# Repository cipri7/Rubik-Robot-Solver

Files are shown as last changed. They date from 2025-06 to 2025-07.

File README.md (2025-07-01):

# Rubik-Robot-Solver

This project solves a Rubik's Cube using a combination of computer vision and robotics. It scans the cube's faces using a camera, determines the cube's state, calculates the solution, and then sends the solution to an Arduino-controlled robot to execute the moves.

The robot in action: https://youtu.be/shVyaf8nSuM?si=lHKmhP8OhFEYzAJg

## Prerequisites

Before you begin, ensure you have the following:

*   **Python 3.6+**
*   **pip** (Python package installer)
*   **A webcam** connected to your computer.
*   **An Arduino** connected to your computer.
*   **6x Nema17 Stepper Motors**
*   **6x A4988 Drivers**
*   **6x 100uF Capacitors**
*   **12V Power Supply**
*   **A Rubik's Cube**

## Installation

1.  **Clone the repository:**

    ```bash
    git clone <repository_url>
    cd Rubik-Robot-Solver
    ```

2.  **Install the required Python packages:**

    ```bash
    pip install -r requirements.txt
    ```

3. **Upload motor_solver.c to Arduino**

4. **Build the electronic circuit as in the schematic file**
5. **Assemble the robot.**

## Configuration

1.  **Calibration:**
    *   Run the `scan_cube.py` script to calibrate the color detection. This step is crucial for accurate color recognition.
    *   The script will prompt you to show each face of the cube (W, R, G, Y, O, B) to the camera. Center the face and press SPACE to capture its color.
    *   If you have a pre-existing calibration, you can skip the calibration by pressing any key other than 'c' when prompted.
    *   The calibration data is saved in `src/calibration.json`.

2.  **Arduino Port:**
    *   Modify the `ARDUINO_PORT` variable in [`src/visualize_cube.py`](https://github.com/cipri7/Rubik-Robot-Solver/blob/main/src/visualize_cube.py) to match the serial port of your Arduino.

    ```python
    # From src/visualize_cube.py
    ARDUINO_PORT = "/dev/cu.usbmodem1101"  # Update as needed
    ```

    *   You can usually find the correct port in the Arduino IDE.

## Usage

1.  **Scan the Cube:**

    *   Run the main script to start the scanning process:

    ```bash
    python src/main.py
    ```

    *   The `scan_cube.py` script will guide you through scanning each face of the Rubik's Cube. Follow the on-screen prompts.
    *   The scanned state will be saved in [`src/scanned_state.json`](https://github.com/cipri7/Rubik-Robot-Solver/blob/main/src/scanned_state.json).

2.  **Visualize and Solve:**

    *   After scanning, the `visualize_cube.py` script will open a window displaying the scanned cube.
    *   You can manually correct any misidentified colors by clicking on the tiles and selecting the correct color.
    *   Press `C` to confirm the cube state. This will print the Kociemba string representation of the cube to the console.
    *   Press `S` to solve the cube. This will calculate the solution using the `kociemba` library and send the solution to the Arduino.

## Troubleshooting

*   **Webcam Issues:** If the webcam is not detected, ensure it is properly connected and that no other applications are using it.  You may need to adjust the `camera_id` in [`src/cube_scanner.py`](https://github.com/cipri7/Rubik-Robot-Solver/blob/main/src/cube_scanner.py).
*   **Color Calibration:** If the colors are not being recognized correctly, recalibrate the color detection using the `scan_cube.py` script. Ensure good lighting conditions during calibration.
*   **Serial Communication:** If the solution is not being sent to the Arduino, double-check the `ARDUINO_PORT` in [`src/visualize_cube.py`](https://github.com/cipri7/Rubik-Robot-Solver/blob/main/src/visualize_cube.py) and ensure the Arduino is properly connected and running the appropriate firmware.

## Code Structure

*   [`src/main.py`](https://github.com/cipri7/Rubik-Robot-Solver/blob/main/src/main.py): Main entry point of the application.
*   [`src/scan_cube.py`](https://github.com/cipri7/Rubik-Robot-Solver/blob/main/src/scan_cube.py): Handles cube scanning and color calibration.
*   [`src/cube_scanner.py`](https://github.com/cipri7/Rubik-Robot-Solver/blob/main/src/cube_scanner.py): Contains the `CubeScanner` class for capturing cube faces.
*   [`src/color_classifier.py`](https://github.com/cipri7/Rubik-Robot-Solver/blob/main/src/color_classifier.py): Contains the `ColorClassifier` class for identifying colors.
*   [`src/visualize_cube.py`](https://github.com/cipri7/Rubik-Robot-Solver/blob/main/src/visualize_cube.py): Visualizes the scanned cube and sends the solution to the Arduino.
*   [`src/motor_controller.py`](https://github.com/cipri7/Rubik-Robot-Solver/blob/main/src/motor_controller.py): Manages serial communication with the Arduino.
*   [`src/calibration.json`](https://github.com/cipri7/Rubik-Robot-Solver/blob/main/src/calibration.json): Stores color calibration data.
*   [`src/scanned_state.json`](https://github.com/cipri7/Rubik-Robot-Solver/blob/main/src/scanned_state.json): Stores the scanned state of the cube.

## Credits

This project utilizes the kociemba library for solving the Rubik's Cube.

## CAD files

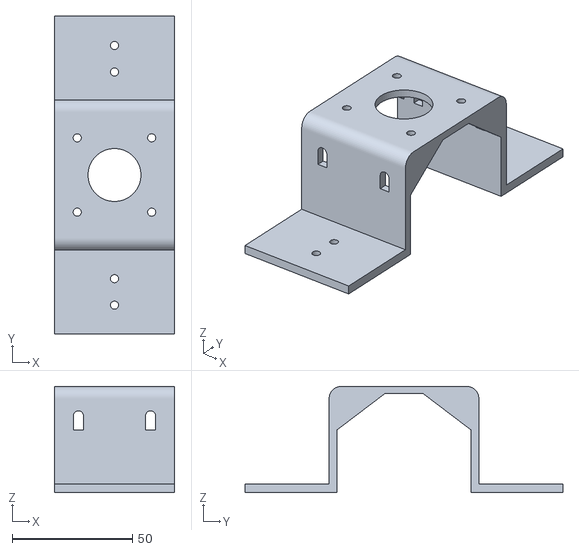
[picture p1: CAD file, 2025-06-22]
stl_files/motor_low_mount.stl
50.0 x 132.3 x 44.2

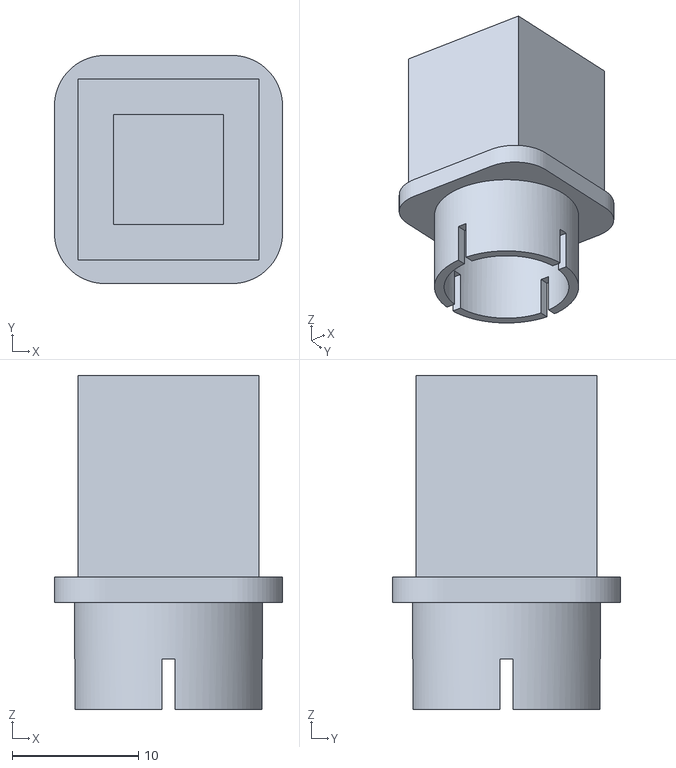
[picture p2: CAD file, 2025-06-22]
stl_files/cube_adapter_B.stl
18.1 x 18.1 x 26.5

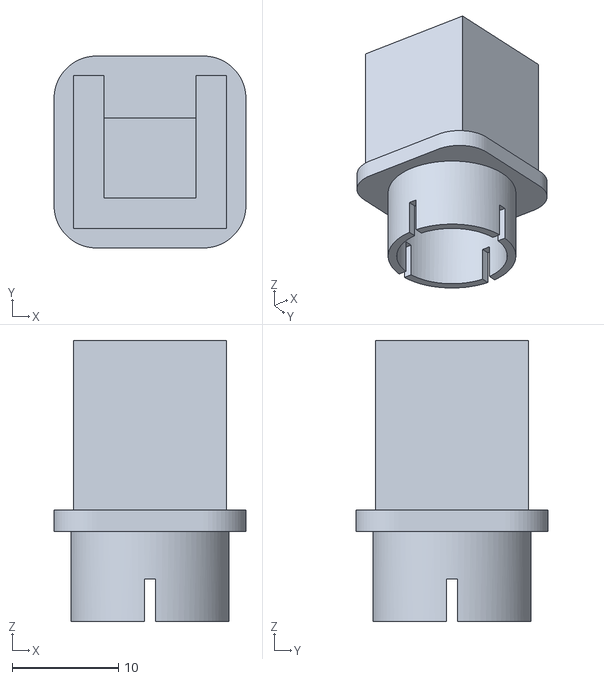
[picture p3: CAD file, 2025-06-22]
stl_files/cube_adapter_A.stl
18.1 x 18.1 x 26.5

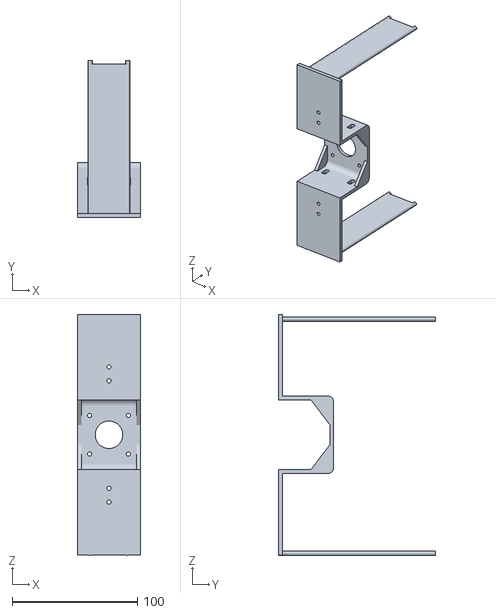
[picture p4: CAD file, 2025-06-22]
stl_files/motor_top_mount.stl
50.0 x 125.8 x 192.7

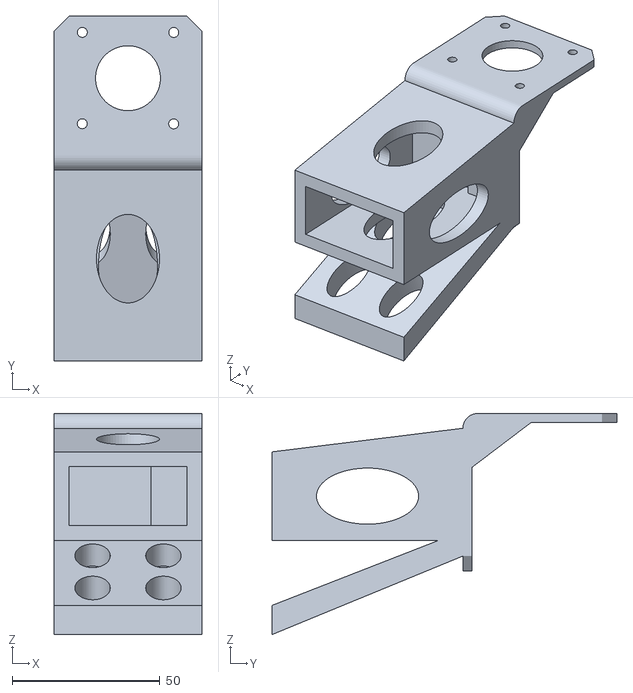
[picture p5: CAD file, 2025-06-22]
stl_files/motor_side_mount.stl
50.0 x 116.7 x 74.9

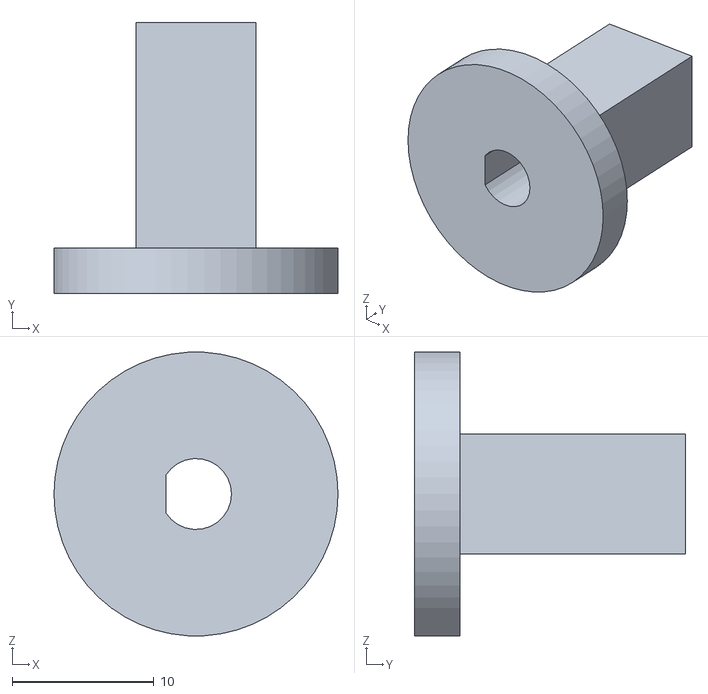
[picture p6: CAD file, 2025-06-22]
stl_files/motor_shaft_support.stl
20.0 x 19.0 x 20.0

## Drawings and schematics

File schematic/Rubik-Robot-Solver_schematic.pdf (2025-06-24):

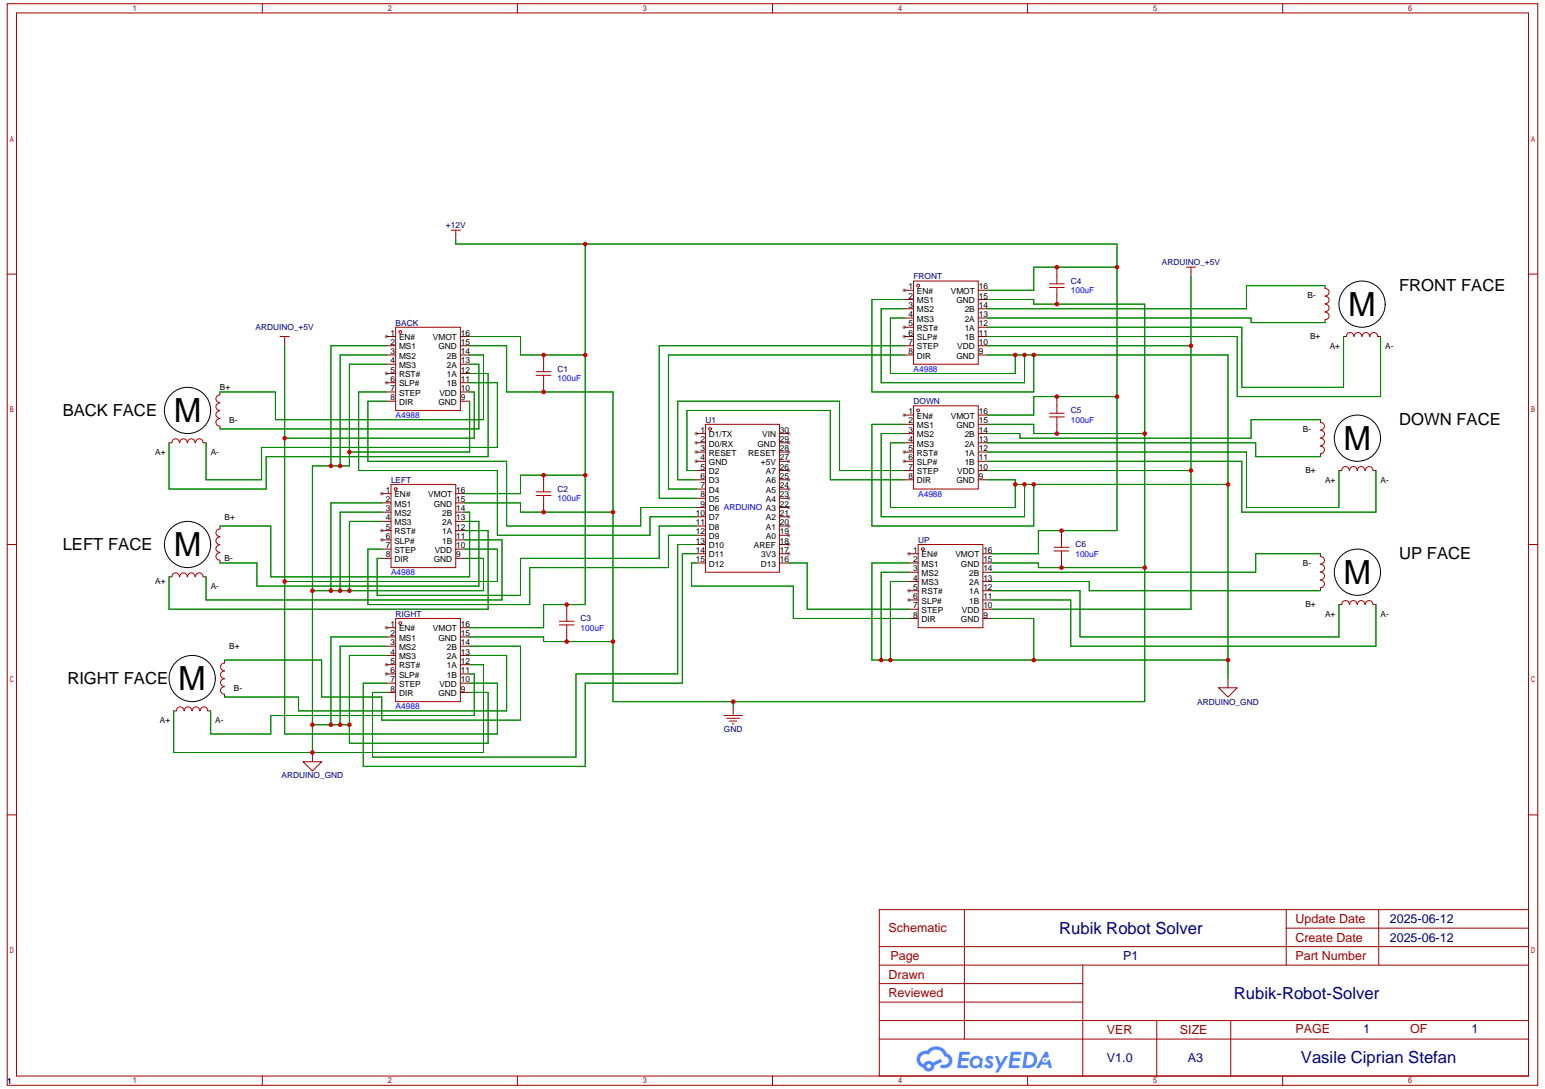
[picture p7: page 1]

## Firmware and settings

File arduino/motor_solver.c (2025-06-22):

#include <AccelStepper.h>

// Stepper motors (STEP, DIR)
AccelStepper stepperU(1, 13, 12);   // Up
AccelStepper stepperD(1, 3, 2);     // Down
AccelStepper stepperF(1, 5, 4);     // Front
AccelStepper stepperB(1, 7, 6);     // Back
AccelStepper stepperL(1, 9, 8);     // Left
AccelStepper stepperR(1, 11, 10);   // Right

// Steps per 90-degree turn
#define STEPS_PER_90_DEG 50 

String inputCommand = "";

void setup() {
  Serial.begin(115200);
  Serial.println("Rubik's Cube Stepper Controller Ready.");
  Serial.println("Enter move string (e.g. UDBFLRRL2UBD3R2U):");

  // Set max speed and acceleration
  stepperU.setMaxSpeed(5000); stepperU.setAcceleration(5000);
  stepperD.setMaxSpeed(5000); stepperD.setAcceleration(5000);
  stepperF.setMaxSpeed(5000); stepperF.setAcceleration(5000);
  stepperB.setMaxSpeed(5000); stepperB.setAcceleration(5000);
  stepperL.setMaxSpeed(5000); stepperL.setAcceleration(5000);
  stepperR.setMaxSpeed(5000); stepperR.setAcceleration(5000);
}

void moveMotor(AccelStepper &motor, int steps) {
  motor.move(steps);
  while (motor.distanceToGo() != 0) {
    motor.run();
  }
}

void processMoves(String command) {
  command.trim();
  Serial.print("Processing: "); Serial.println(command);

  for (int i = 0; i < command.length(); i++) {
    char move = command[i];
    int steps = STEPS_PER_90_DEG;

    // If next character is '2' or '3', apply the multiplier
    if (i + 1 < command.length()) {
      char nextChar = command[i + 1];
      if (nextChar == '2') {
        steps *= 2;
        i++;
      } else if (nextChar == '3') {
        steps *= 3;
        i++;
      }
    }

    switch (move) {
      case 'U': moveMotor(stepperU, steps); break;
      case 'D': moveMotor(stepperD, steps); break;
      case 'F': moveMotor(stepperF, steps); break;
      case 'B': moveMotor(stepperB, steps); break;
      case 'L': moveMotor(stepperL, steps); break;
      case 'R': moveMotor(stepperR, steps); break;
      default:
        Serial.print("Invalid move: "); Serial.println(move);
    }
  }

  Serial.println("Done. Enter another move string:");
}

void loop() {
  if (Serial.available()) {
    inputCommand = Serial.readStringUntil('\n');
    processMoves(inputCommand);
  }
}

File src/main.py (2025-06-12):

# From main.py
import subprocess
import cv2
from scan_cube import run_scanner

def main():
    print("=== Rubik Cube Solver App ===")

    # Step 1: Scan the cube
    run_scanner()

    # Step 2: Launch the visualizer for confirmation/modification
    subprocess.run(["python", "visualize_cube.py"])

    print("Done. Cube should now be solved if [S] was pressed in visualizer.")

if __name__ == "__main__":
    main()

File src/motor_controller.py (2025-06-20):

import serial
import time

class MotorController:
    def __init__(self, port, baud_rate=115200):
        self.port = port
        self.baud_rate = baud_rate
        self.arduino = None

    def connect(self):
        try:
            self.arduino = serial.Serial(self.port, self.baud_rate)
            time.sleep(2)  # Wait for Arduino to initialize
            print("Connected to Arduino.")
            return True
        except serial.SerialException as e:
            print(f"Error connecting to Arduino: {e}")
            return False

    def disconnect(self):
        if self.arduino:
            self.arduino.close()
            print("Disconnected from Arduino.")

    def send_solution(self, solution):
        if not self.arduino:
            print("Not connected to Arduino.")
            return

        print("Sending solution to Arduino:", solution)
        self.arduino.write((solution + '\n').encode())

        # Wait for Arduino to respond with "Done"
        while True:
            if self.arduino.in_waiting:
                line = self.arduino.readline().decode().strip()
                print("Arduino:", line)
                if "Done" in line:
                    break

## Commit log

2025-06-22 added arduino files
2025-06-22 added stl files
    [cube_adapter_A.stl, cube_adapter_B.stl, motor_low_mount.stl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]
2025-06-24 added schematic file
